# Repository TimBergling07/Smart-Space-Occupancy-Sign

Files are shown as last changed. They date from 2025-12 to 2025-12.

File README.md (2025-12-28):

# **Smart Space Occupancy Sign**

### **An Intelligent Multi-modal Sensing System for Real-time Space Management**

## **1. Project Overview**

This project addresses the conflict between "Displayed Status" and "Actual Usage" in shared spaces (classrooms, meeting rooms, labs). We developed an intelligent occupancy sign that uses **Multi-modal Heterogeneous Fusion** to detect human presence with high reliability, even in "static" or "silent" scenarios.

## **2. System Architecture**

The system adopts a distributed control architecture:

* **Audio AI Module (ESP32)**: Captures acoustic features and runs a Random Forest classifier to identify human activities (talking, typing, moving).
* **Microwave Radar Module (Arduino Uno)**: Detects micro-movements (breathing, slight shifting) via 24GHz microwave Doppler effect.
* **Indicator System**: A tri-color LED system (Red: Occupied, Yellow: Leaving soon, Green: Vacant).

## **3. Key Technical Highlights**

### **3.1 AI Audio Feature Engineering**

To overcome the limitations of far-field sound pickup, we implemented custom non-linear gain compensation:

* **RMS Factor (*5.0)**: Amplifies the root-mean-square energy of the signal to capture faint distant sounds.
* **Burst Factor (*4.0)**: Enhances transient pulse detection (e.g., pen clicking, page turning).
* **Classifier**: A Random Forest model optimized for low-power edge deployment on ESP32.

### **3.2 Heterogeneous Logic Fusion**

We designed an **Asynchronous Trigger-and-Hold** logic to handle the "Blind Zone" and "Static Presence" issues:

1. **Fast Wake-up**: The system triggers "Occupied" if *either* the Radar or AI detects a signal within a 6-second window.
2. **Robust Maintenance**: A **30-minute cooldown timer** prevents frequent flickering. The status only reverts to "Vacant" if no signals are detected by *both* sensors for the entire duration.

## **4. Repository Structure**

```text
├── ESP32-Audio-AI/          # Source code for AI inference & sound processing
├── Arduino-Uno-Radar/       # Radar signal processing & LED control logic
└── Hardware/            # 3D modeling files (.STL & .STEP) for the enclosure

```

## **5. Hardware Requirements**

* **Microcontrollers**: ESP32-DevKitC, Arduino Uno R3
* **Sensors**: INMP441 (I2S Digital Microphone), LD2402 (24GHz Microwave Radar)
* **Outputs**: RGB LED Strip / Matrix
* **Enclosure**: Custom 3D-printed PLA housing

## **6. Reflection & Future Work**

* **Current Limitation**: In extreme silence (e.g., deep sleep without movement), detection remains a challenge.
* **Optimization**: Future iterations will migrate to a single-chip solution (ESP32-S3) to reduce power consumption and latency.

## **7. Authors & Acknowledgments**

Developed by a team of students from **Shanghai Jiao Tong University (SJTU)**:

* **Wang Yanzhe (Project Lead & AI Developer)**
* Xiong Jinyi(AI Developer), Li Zeyu(3D-Model Designer), Pan Jingyuan(Electronic Control), Dong Yunhe(Report and PPT Making).

Special thanks to **SJTU teachers:Yang Li and Wang Zechen** for providing instructions, testing environment and equipment.

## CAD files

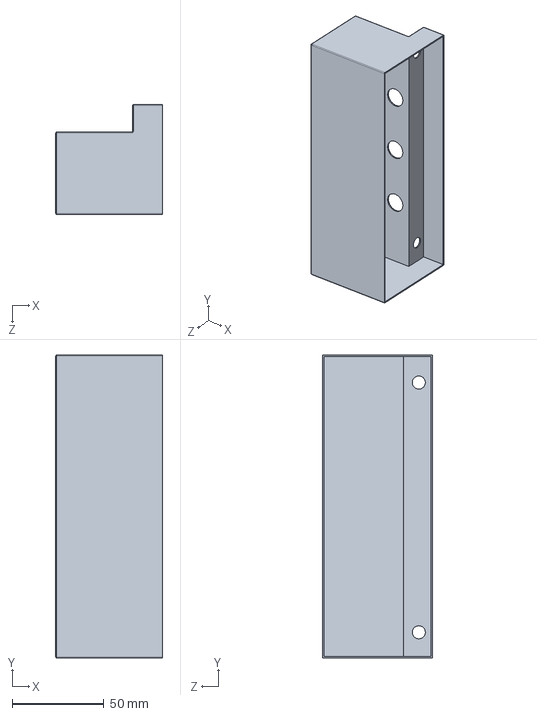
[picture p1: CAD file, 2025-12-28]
Smart Space Occupancy Sign/Hardware/门牌.SLDPRT
58.0 x 165.0 x 60.0 mm

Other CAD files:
Smart Space Occupancy Sign/Hardware/门牌.STL

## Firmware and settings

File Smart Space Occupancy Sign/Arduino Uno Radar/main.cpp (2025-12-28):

#include <SoftwareSerial.h>

// 1. 硬件参数定义（严格匹配官方手册）
SoftwareSerial radarSerial(2, 3);  // D2=RX（接雷达TX），D3=TX（接雷达RX）
const int RED_LED = 4;
const int YELLOW_LED = 5;
const int GREEN_LED = 6;
const int RADAR_IO_PIN = 7;  // 雷达GPIO状态引脚（J2Pin2）

// 2. 状态变量
bool isHumanPresent = false;       
bool lastHumanState = false;       
unsigned long noHumanStartTime = 0;
unsigned long lastRadarDataTime = 0;
String lastRadarData = "";         // 保存上一次的雷达原始数据（解决错位）
float lastDistanceM = 0.0;         // 保存上一次的解析距离（避免归零）
const unsigned long RADAR_TIMEOUT = 3000;  
const float DISTANCE_THRESHOLD = 100.0;  // 1米=100cm


void setup() {
  Serial.begin(9600);  
  radarSerial.begin(115200);  
  pinMode(RED_LED, OUTPUT);
  pinMode(YELLOW_LED, OUTPUT);
  pinMode(GREEN_LED, OUTPUT);
  pinMode(RADAR_IO_PIN, INPUT);  

  setSingleLight(GREEN_LED);
  Serial.println("=== HLK-LD2402 人体检测系统（调试版）初始化完成 ===");
  Serial.println("提示：1. 确保雷达供电3.3V  2. 先执行「自动门限生成」");
  Serial.println("      3. 无人判定：\"OFF\" 或 距离>1米");
  Serial.println("      4. 调试日志将显示空格处理前后的原始数据");
  Serial.println("----------------------------------------");

  // 初始化：先读取一次雷达数据，避免首次打印空数据
  readRadarState();
  delay(165);  // 匹配雷达数据刷新周期
}


// 修复核心：调整“打印-读取”顺序，先打印上一次数据，再读新数据
void loop() {
  radarMonitor();    // 步骤1：打印【上一次】的雷达数据（解决错位）
  readRadarState();  // 步骤2：读取【新的】雷达数据（更新状态）
  controlLights();   
  delay(165);        
}


// 3. 读取雷达状态（优化解析容错性+调试空格处理）
void readRadarState() {
  String radarData = "";
  unsigned long readStartTime = millis();
  
  // 读取串口数据（增加超时，避免卡滞）
  while (radarSerial.available() > 0 && (millis() - readStartTime) < 100) {
    char c = radarSerial.read();
    if (c == '\n') break;  // 换行符结束
    radarData += c;
    delay(1);
  }

  // ========== 调试打印1：原始数据（未处理空格） ==========
  Serial.print("[调试1] 原始雷达数据（未去空格）：");
  Serial.println("[" + radarData + "]"); // 用[]包裹，直观看到空格/空白符

  // 第一步：清理所有空白字符（首尾+中间空格、回车、制表符）
  radarData = removeAllWhitespace(radarData);

  // ========== 调试打印2：原始数据（处理所有空格后） ==========
  Serial.print("[调试2] 雷达数据（处理所有空格后）：");
  Serial.println("[" + radarData + "]");

  lastRadarData = radarData;  // 保存新读取的原始数据（供下一次打印）
  lastRadarDataTime = millis();

  // 严格校验数据格式，避免解析错误
  if (radarData.startsWith("distance:")) {
    // 提取距离子串（从"distance:"后开始）
    String distStrRaw = radarData.substring(9);
    
    // ========== 调试打印3：距离子串（未处理空格） ==========
    Serial.print("[调试3] 距离子串（未去空格）：");
    Serial.println("[" + distStrRaw + "]");

    // 第二步：清理距离子串的所有空白字符
    String distStr = removeAllWhitespace(distStrRaw);

    // ========== 调试打印4：距离子串（处理所有空格后） ==========
    Serial.print("[调试4] 距离子串（处理所有空格后）：");
    Serial.println("[" + distStr + "]");

    // 容错：判断是否为有效数字
    if (isNumeric(distStr)) {
      float distanceCm = distStr.toFloat();
      lastDistanceM = distanceCm / 100.0;  // 保存有效距离
      // 判定有人/无人
      isHumanPresent = (distanceCm <= DISTANCE_THRESHOLD);
      // ========== 调试打印5：解析成功日志 ==========
      Serial.print("[调试5] 距离解析成功：");
      Serial.print(distanceCm);
      Serial.print("cm → ");
      Serial.print(lastDistanceM);
      Serial.println("m | 有人判定：" + String(isHumanPresent ? "是" : "否"));
    } else {
      // 非数字时，沿用上次距离，避免归零
      Serial.println("[解析异常] 距离格式错误（含非数字字符），沿用上次距离：" + String(lastDistanceM) + "m");
    }
  } else if (radarData == "OFF") {
    isHumanPresent = false;
    lastDistanceM = 0.0;  // OFF时距离置0
    Serial.println("[调试5] 检测到OFF状态，距离置0 | 有人判定：否");
  } else {
    // 非预期数据，用GPIO备用检测，沿用上次距离
    isHumanPresent = (digitalRead(RADAR_IO_PIN) == HIGH);
    Serial.println("[解析异常] 非预期数据（非distance/OFF），用GPIO判断 | 有人判定：" + String(isHumanPresent ? "是" : "否"));
  }

  // 状态变化时重置计时
  if (isHumanPresent != lastHumanState) {
    if (!isHumanPresent) noHumanStartTime = millis();
    lastHumanState = isHumanPresent;
  }
}


// 4. 雷达异常监测（打印上一次的有效数据，解决错位）
void radarMonitor() {
  unsigned long currentTime = millis();
  bool radarTimeout = (currentTime - lastRadarDataTime) > RADAR_TIMEOUT;

  Serial.print("\n【雷达监测】");
  if (radarTimeout) {
    Serial.println("状态：❌ 雷达超时（无串口数据）");
    Serial.println("  排查：接线/TX→D2/RX→D3/波特率115200");
  } else {
    Serial.println("状态：✅ 串口数据正常");
    Serial.print("  原始数据：");
    Serial.println(lastRadarData);  // 打印上一次的原始数据
  }

  // 打印核心状态（使用保存的距离，避免归零）
  Serial.print("【当前状态】有人：");
  Serial.print(isHumanPresent ? "是" : "否");
  Serial.print(" | 探测距离：");
  Serial.print(lastDistanceM);
  Serial.print("m | 无人持续时间：");
  Serial.print(isHumanPresent ? 0 : (currentTime - noHumanStartTime) / 1000.0);
  Serial.println("s");
  Serial.println("----------------------------------------");
}


// 5. 灯光控制（逻辑不变）
void controlLights() {
  unsigned long currentTime = millis();
  bool radarTimeout = (currentTime - lastRadarDataTime) > RADAR_TIMEOUT;

  if (radarTimeout) {
    digitalWrite(YELLOW_LED, (currentTime % 500) < 250 ? HIGH : LOW);
    digitalWrite(RED_LED, LOW);
    digitalWrite(GREEN_LED, LOW);
    return;
  }

  if (isHumanPresent) {
    setSingleLight(RED_LED);
  } else {
    unsigned long noHumanDuration = currentTime - noHumanStartTime;
    if (noHumanDuration < 25000) setSingleLight(RED_LED);
    else if (noHumanDuration <= 30000) setSingleLight(YELLOW_LED);
    else setSingleLight(GREEN_LED);
  }
}


// 6. 工具函数：移除字符串中所有空白字符（空格、回车、制表符、换行）
String removeAllWhitespace(String str) {
  String result = "";
  for (int i = 0; i < str.length(); i++) {
    char c = str.charAt(i);
    // 排除空格(32)、回车(13)、制表符(9)、换行(10)
    if (c != ' ' && c != '\r' && c != '\t' && c != '\n') {
      result += c;
    }
  }
  return result;
}


// 7. 工具函数：判断字符串是否为有效数字（含小数）
bool isNumeric(String str) {
  if (str.length() == 0) return false; // 空字符串直接返回false
  bool hasDecimal = false;
  for (int i = 0; i < str.length(); i++) {
    char c = str.charAt(i);
    // 允许数字和单个小数点
    if (!isDigit(c)) {
      if (c == '.' && !hasDecimal) {
        hasDecimal = true;
      } else {
        return false; // 含非数字/多个小数点，返回false
      }
    }
  }
  return true;
}


// 8. 工具函数：单独点亮指定LED，熄灭其他
void setSingleLight(int targetLed) {
  digitalWrite(RED_LED, targetLed == RED_LED ? HIGH : LOW);
  digitalWrite(YELLOW_LED, targetLed == YELLOW_LED ? HIGH : LOW);
  digitalWrite(GREEN_LED, targetLed == GREEN_LED ? HIGH : LOW);
}

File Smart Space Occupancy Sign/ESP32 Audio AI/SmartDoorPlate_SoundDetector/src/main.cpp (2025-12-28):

#include <Arduino.h>
#include <driver/i2s.h>
#include "feature_extractor.h"
#include "model.h"
#include "soc/rtc_wdt.h"

// --- 硬件引脚 (最稳配置) ---
#define I2S_WS 25
#define I2S_SD 27
#define I2S_SCK 26
#define I2S_PORT I2S_NUM_0

// --- 采样配置 (2秒窗口对齐训练集) ---
#define SAMPLE_RATE 16000
#define TOTAL_SAMPLES 32000 
int16_t audioBuffer[TOTAL_SAMPLES]; 
float features[4];

// --- 状态机配置 (让灯光更稳) ---
enum RoomStatus { EMPTY, OCCUPIED };
RoomStatus currentStatus = EMPTY;
int confidence = 0;
const int OCCUPIED_THRESHOLD = 3; // 连续3次(6s)判定有人 -> 亮灯
const int EMPTY_THRESHOLD = 6;    // 连续6次(12s)判定没人 -> 灭灯 (稍微调快一点点)

// 实例化你刚刚重新练好的随机森林
Eloquent::ML::Port::RandomForest classifier;

void setup() {
    // 强制关闭看门狗，防止 FFT 运算时重启
    disableCore0WDT(); 
    disableLoopWDT();
    rtc_wdt_protect_off();
    rtc_wdt_disable();
    
    Serial.begin(115200);
    pinMode(2, OUTPUT); // ESP32 板载蓝灯 (IO2)

    // I2S 驱动安装
    i2s_config_t i2s_config = {
        .mode = (i2s_mode_t)(I2S_MODE_MASTER | I2S_MODE_RX),
        .sample_rate = SAMPLE_RATE,
        .bits_per_sample = I2S_BITS_PER_SAMPLE_16BIT,
        .channel_format = I2S_CHANNEL_FMT_ONLY_LEFT,
        .communication_format = (i2s_comm_format_t)(I2S_COMM_FORMAT_I2S_MSB | I2S_COMM_FORMAT_I2S),
        .intr_alloc_flags = ESP_INTR_FLAG_LEVEL1,
        .dma_buf_count = 8,
        .dma_buf_len = 1024,
        .use_apll = false
    };

    i2s_pin_config_t pin_config = {
        .bck_io_num = I2S_SCK,
        .ws_io_num = I2S_WS,
        .data_out_num = -1,
        .data_in_num = I2S_SD
    };

    i2s_driver_install(I2S_PORT, &i2s_config, 0, NULL);
    i2s_set_pin(I2S_PORT, &pin_config);
    
    Serial.println("\n======================================");
    Serial.println(">>>  AI 随机森林决策系统：正式启动 <<<");
    Serial.println(">>> 状态机、2s窗口、增益补偿已就绪 <<<");
    Serial.println("======================================");
}

void loop() {
    size_t bytes_read = 0;
    size_t total_read = 0;

    Serial.println("\n[监听中...] 正在采集 2 秒环境音频...");

    // 1. 采集 2 秒数据
    // 请确保这里的 while 括号是完整的
    while (total_read < TOTAL_SAMPLES) {
        rtc_wdt_feed(); // 喂狗，防止采集期间重启
        size_t to_read = (TOTAL_SAMPLES - total_read) > 1024 ? 1024 : (TOTAL_SAMPLES - total_read);
        i2s_read(I2S_PORT, &audioBuffer[total_read], to_read * sizeof(int16_t), &bytes_read, portMAX_DELAY);
        total_read += (bytes_read / sizeof(int16_t));
    }

    // 2. 提取四维特征 (注意：feature_extractor.h 里 threshold 必须也是 800)
    FeatureExtractor::extractFeatures(audioBuffer, TOTAL_SAMPLES, features);

    // 3. AI 推理
    int prediction = classifier.predict(features);

    // 4. 状态机逻辑
    if (prediction == 1) { // AI 判定有人 (Occupied)
        if (currentStatus == EMPTY) {
            confidence++;
            Serial.printf("检测到疑似信号... 置信度: %d/%d\n", confidence, OCCUPIED_THRESHOLD);
            if (confidence >= OCCUPIED_THRESHOLD) {
                currentStatus = OCCUPIED;
                confidence = 0;
                Serial.println(">>> 状态切换：【有人】 (Occupied)");
            }
        } else {
            confidence = 0; // 已经在有人状态，重置计数器
        }
    } else { // AI 判定没人 (Empty)
        if (currentStatus == OCCUPIED) {
            confidence++;
            Serial.printf("环境变安静了... 确认中: %d/%d\n", confidence, EMPTY_THRESHOLD);
            if (confidence >= EMPTY_THRESHOLD) {
                currentStatus = EMPTY;
                confidence = 0;
                Serial.println(">>> 状态切换：【无人】 (Empty)");
            }
        } else {
            confidence = 0;
        }
    }

    // 5. 串口报告 (方便演示时观察特征值)
    Serial.print("RMS: "); Serial.print(features[0], 4);
    Serial.print(" | Burst: "); Serial.print((int)features[1]);
    Serial.print(" | B_Str: "); Serial.print(features[2], 1);
    Serial.print(" | Voice: "); Serial.print(features[3] * 100, 2);
    Serial.printf("%% | 判定: %s\n", classifier.idxToLabel(prediction));

    // 6. 执行动作 (蓝灯控制)
    digitalWrite(2, (currentStatus == OCCUPIED ? HIGH : LOW));

    yield(); // 给系统留出时间处理后台任务
} // <--- 重点检查这个最后的大括号！
